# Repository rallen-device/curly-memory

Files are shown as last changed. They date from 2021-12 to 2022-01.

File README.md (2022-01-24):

# CURLY-MEMORY

Open source eurorack hardware using an ESP32.

ESP32 acts like anything you want, just reprogram with new firmware.

## Features

### INPUTS:
 - Analogue input x4
  - 1/8" jack x3 (IN0, IN1, IN2)
  - 2.54mm pin header x2 (IN2, IN3)

### OUTPUTS:
 - Analogue output x4
  - 1/8" jack x3 (OUT0, OUT1, OUT2)
  - 2.54mm pin header x3 (OUT2, OUT3)

### CONTROLS:
 - Potentiometer input x4
 - Tactile switch x2

### OTHER:
 - Feedback resistor (digital pot connecting OUT0 to IN0)
 - Digital pot output on 2.54mm pin header
 - Dry/wet mixer (IN0 + OUT0 - connecting to digital pot)
 - WS2812B LEDs x2

### POWER:
 - Eurorack standard 10 pin IDC connector
 - 12V input

### FIRMWARE:
 - ESP-IDF or Arduino

## Images

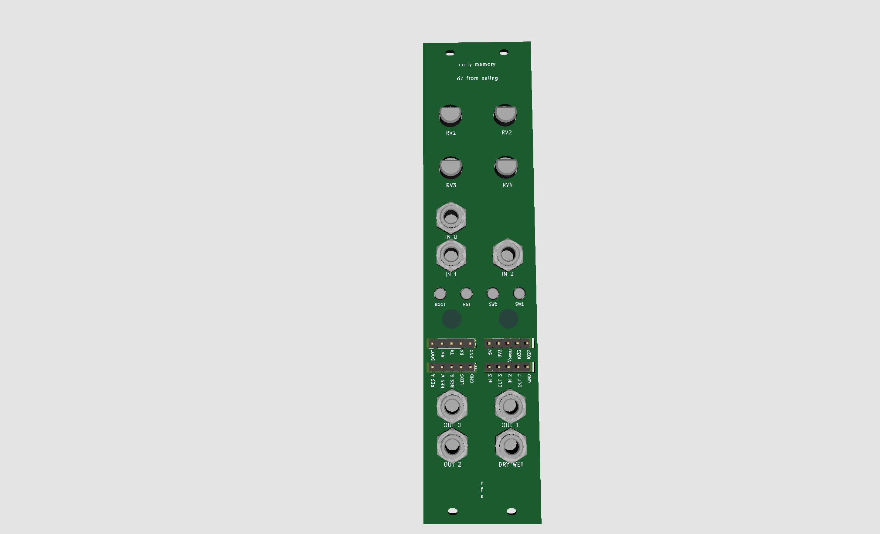
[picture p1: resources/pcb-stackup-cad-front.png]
main-cad

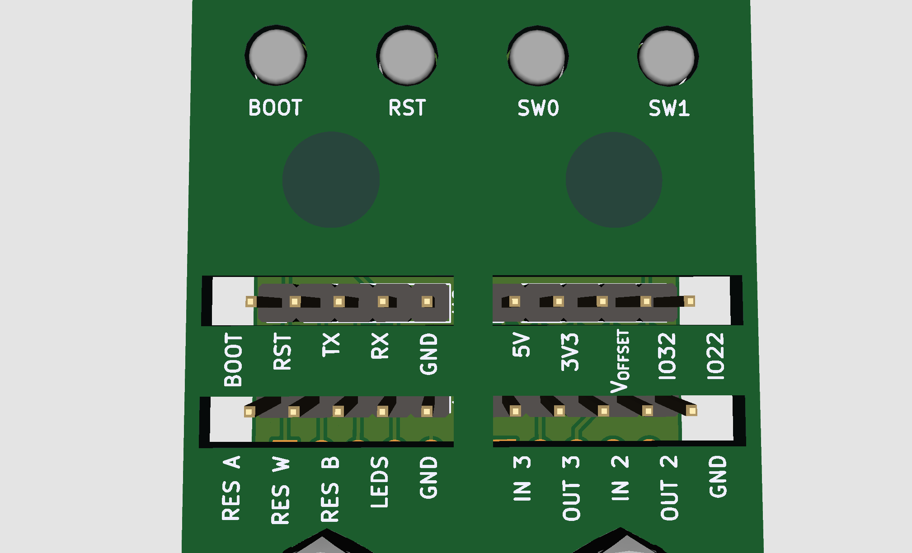
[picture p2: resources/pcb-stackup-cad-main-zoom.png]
zoom-cad

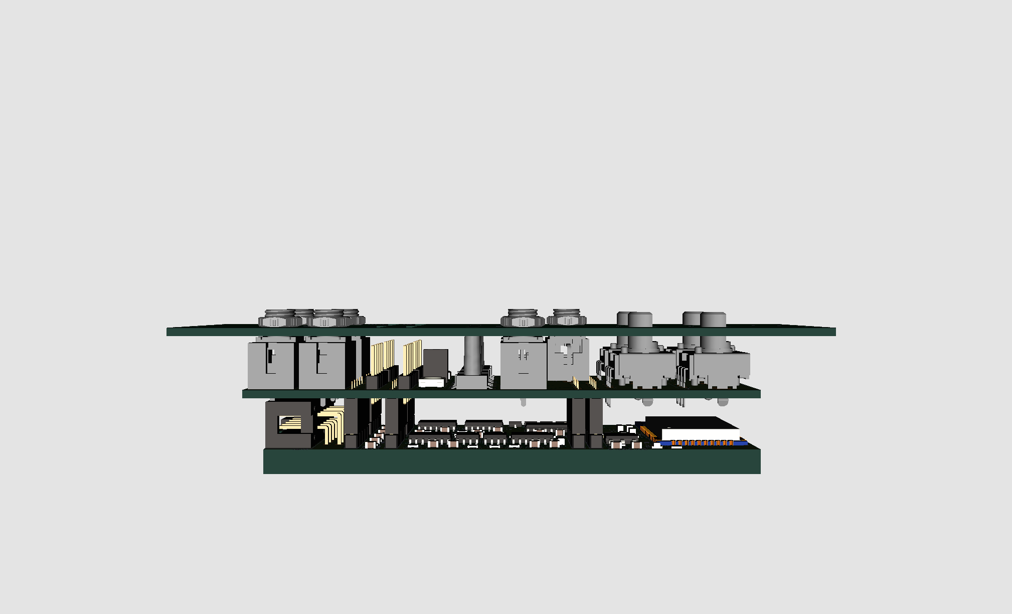
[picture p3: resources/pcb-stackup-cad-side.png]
side-cad


## References

- https://www.electrosmash.com/pt2399-analysis
- https://intellijel.com/support/eurorack-101/
- https://docs.espressif.com/projects/esp-idf/en/latest/esp32/api-reference/peripherals/spi_master.html

## Influences

- https://ornament-and-cri.me/

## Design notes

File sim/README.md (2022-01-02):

# Simulations

All simulations are done using http://www.falstad.com/circuit/, open the files on the website to view the simulations

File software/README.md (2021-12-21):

# Firmware

Firmware runs on an esp32. The firmware is open source and can be modified to change the functionality.

## Installation and Usage

- Clone this repo
- Install esp-idf to compile
- Run ~/esp/esp-idf/export.sh to import the idf tools to the command line
- Run idf.py build to build the code

Follow the steps on ['ESP-IDF Get Started'](https://docs.espressif.com/projects/esp-idf/en/latest/esp32/get-started/index.html#installation-step-by-step) to install the esp-idf which is used to compile.

## Troubleshooting

#### Installing esp-idf on macos

Only version that worked was 'release/v4.2' to get this run the following commands:
$ git checkout --track origin/release/v4.2
$ git submodule update --recursive

#### USB device not showing up on macos

- Install CP2102 driver from https://www.silabs.com/developers/usb-to-uart-bridge-vcp-drivers
- During install it request to 'Open Security and Privacy', open it and click the lock in the bottom left, then click allow where it says that VCP driver is requesting to make changes

# Licence
For licence see main readme

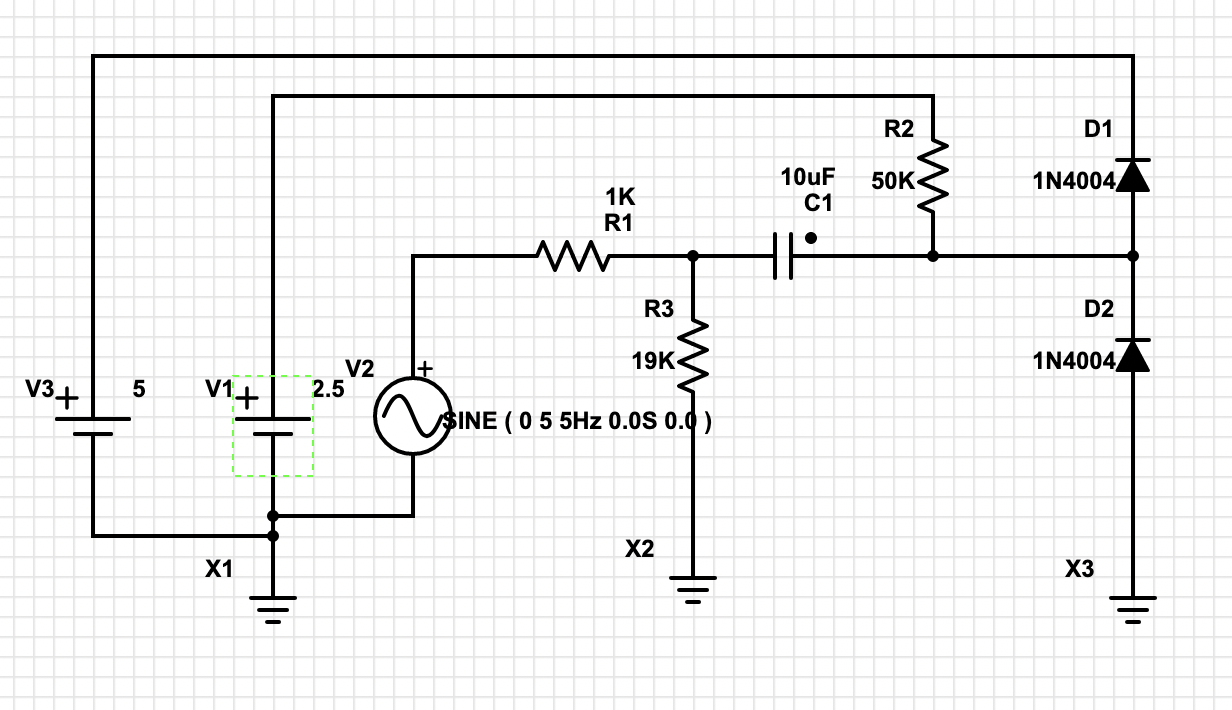
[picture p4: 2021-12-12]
resources/osc_in_circuit.png

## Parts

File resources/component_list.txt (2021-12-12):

ADC - option a - https://www.ti.com/store/ti/en/p/product/?p=ADC082S021CIMM/NOPB
ADC - option b - https://uk.farnell.com/microchip/mcp3002-i-sn/adc-10bit-2-7v-2ch-spi-8soic/dp/1834969?st=mcp3002
1/8 Jack - ACJM-MV35-2S - https://uk.farnell.com/amphenol-sine-tuchel/acjm-mv35-2s/phone-connector-mono-jack-2pos/dp/3280971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

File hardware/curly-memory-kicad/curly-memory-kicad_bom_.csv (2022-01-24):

Component | Part | Description | References | Value | Footprint | Quantity Per PCB | Datasheet | MF | MFPN | Material | Voltage | Tolerance
1 | C | Unpolarized capacitor | C201 C202 C203 C301 C302 C303 | 22pF | C_0805_2012Metric_Pad1.18x1.45mm_HandSolder | 6 |  | Samsung | CL21C220JBANNNC | CG0 / NP0 | 50V
2 | C_2 | Unpolarized capacitor | C101 C103 C104 C105 C106 C108 C109 C206 C207 C309 C310 C401 C408 | 100nF | C_0805_2012Metric_Pad1.18x1.45mm_HandSolder | 13 | ~ | Samsung | CL21B104KBCNNNC | X7R | 50V
3 | C |  | C102 C110 C304 C305 C306 | 1uF | C_0805_2012Metric_Pad1.18x1.45mm_HandSolder | 5 |  | Samsung | CL21B105KBFNNNE | X7R | 50V
4 | C |  | C402 C403 C404 C409 C410 | 10uF | C_0805_2012Metric_Pad1.18x1.45mm_HandSolder | 5 |  | Murata | GRM21BR61H106KE43L | X5R | 50V
5 | BAV99 |  | D201 D202 D203 D204 | BAV99 | SOT-23 | 4 | https://assets.nexperia.com/documents/data-sheet/BAV99_SER.pdf
6 | LED | Light emitting diode | D403 D404 | LED | LED_0805_2012Metric_Pad1.15x1.40mm_HandSolder | 2 | ~ | Kingbright | KP-2012EC
7 | D |  | D401 D402 | S1A | D_SMA | 2
8 | R | Resistor | R107 R207 R208 R209 | 100R | R_0805_2012Metric_Pad1.20x1.40mm_HandSolder | 4 | ~ | Multicomp | MCWR08X1000FTL |  |  | 1%
9 | R | Resistor | R403 R404 | 150R | R_0805_2012Metric_Pad1.20x1.40mm_HandSolder | 2 | ~ | Multicomp | MCWR08X1500FTL |  |  | 1%
10 | R_1 | Resistor | R101 R102 R103 R104 R105 R106 | 1K | R_0805_2012Metric_Pad1.20x1.40mm_HandSolder | 6 | ~ | Multicomp | MCWR08X1001FTL |  |  | 1%
11 | R | Resistor | R204 R205 R206 R301 R302 R303 | 47K | R_0805_2012Metric_Pad1.20x1.40mm_HandSolder | 6 | ~ | Multicomp | MCWR08X4702FTL |  |  | 1%
12 | R | Resistor | R402 | 56K | R_0805_2012Metric_Pad1.20x1.40mm_HandSolder | 1 | ~ | Multicomp | MCWR08X5602FTL |  |  | 1%
13 | R | Resistor | R108 R201 R202 R203 R304 R305 R306 R307 R308 R309 R401 | 100K | R_0805_2012Metric_Pad1.20x1.40mm_HandSolder | 11 | ~ | Multicomp | MCWR08X1003FTL |  |  | 1%
14 | ESP32-WROOM-32 |  | U102 | ESP32-WROOM-32 | ESP32-WROOM-32 | 1 | https://www.espressif.com/sites/default/files/documentation/esp32-wroom-32_datasheet_en.pdf
15 | MCP3008 |  | U101 | MCP3008-I/SL | SOIC-16_3.9x9.9mm_P1.27mm | 1 | http://ww1.microchip.com/downloads/en/DeviceDoc/21295d.pdf
16 | MCP42010 | Dual Digital Potentiometer, SPI interface, 256 taps, 10 kohm | U105 U106 | MCP42010-I/SL | SOIC-14_3.9x8.7mm_P1.27mm | 2 | http://ww1.microchip.com/downloads/en/DeviceDoc/11195c.pdf
17 | MCP4822 |  | U103 U104 | MCP4822-E/SN | SOIC-8_3.9x4.9mm_P1.27mm | 2 | http://ww1.microchip.com/downloads/en/DeviceDoc/20002249B.pdf
18 | MCP6004 | 1MHz, Low-Power Op Amp, DIP-14/SOIC-14/TSSOP-14 | U201 U301 | MCP6004-I/SL | SOIC-14_3.9x8.7mm_P1.27mm | 2 | http://ww1.microchip.com/downloads/en/DeviceDoc/21733j.pdf
19 | NCP1117-3.3_SOT223 | 1A Low drop-out regulator, Fixed Output 3.3V, SOT-223 | U402 | NCP1117-3.3_SOT223 | SOT-223-3_TabPin2 | 1 | http://www.onsemi.com/pub_link/Collateral/NCP1117-D.PDF | STMICROELECTRONICS | LD1117S33TR |  | 3V3
20 | NCP1117-5.0_SOT223 | 1A Low drop-out regulator, Fixed Output 5V, SOT-223 | U401 | NCP1117-5.0_SOT223 | SOT-223-3_TabPin2 | 1 | http://www.onsemi.com/pub_link/Collateral/NCP1117-D.PDF | STMICROELECTRONICS | LD1117S50TR |  | 5V
Component Groups: | 20
Component Count: | 77
Fitted Components: | 77
Number of PCBs: | 1
Total components: | 77
Schematic Version:
Schematic Date:
PCB Variant: | default
BoM Date: | Sunday, 16 January 2022 at 09:43:23
Schematic Source: | curly-memory-kicad.kicad_sch
KiCad Version: | Eeschema (6.0.0-0)

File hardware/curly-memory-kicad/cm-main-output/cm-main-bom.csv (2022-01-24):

Component | Description | References | Value | Footprint | Quantity Per PCB | Datasheet | MF | MFPN | Material | Voltage | Tolerance
1 | Unpolarized capacitor | C201 C202 C203 C301 C302 C303 | 22pF | C_0805_2012Metric_Pad1.18x1.45mm_HandSolder | 6 |  | Samsung | CL21C220JBANNNC | CG0 / NP0 | 50V
2 | Unpolarized capacitor | C101 C103 C104 C105 C106 C108 C109 C206 C207 C309 C310 C401 C408 | 100nF | C_0805_2012Metric_Pad1.18x1.45mm_HandSolder | 13 | ~ | Samsung | CL21B104KBCNNNC | X7R | 50V
3 | Unpolarized capacitor | C102 C110 C304 C305 C306 | 1uF | C_0805_2012Metric_Pad1.18x1.45mm_HandSolder | 5 |  | Samsung | CL21B105KBFNNNE | X7R | 50V
4 | Unpolarized capacitor | C402 C403 C404 C409 C410 | 10uF | C_0805_2012Metric_Pad1.18x1.45mm_HandSolder | 5 |  | Murata | GRM21BR61H106KE43L | X5R | 50V
5 | BAV99 Diode | D201 D202 D203 D204 | BAV99 | SOT-23 | 4 | https://assets.nexperia.com/documents/data-sheet/BAV99_SER.pdf | ROHM | BAV99HMT116
6 | Light emitting diode | D403 D404 | LED | LED_0805_2012Metric_Pad1.15x1.40mm_HandSolder | 2 | ~ | Kingbright | KP-2012EC
7 | S1A Diode | D401 D402 | S1A | D_SMA | 2 |  | Vishay | S1A-E3/61T
8 | Resistor | R107 R207 R208 R209 | 100R | R_0805_2012Metric_Pad1.20x1.40mm_HandSolder | 4 | ~ | Multicomp | MCWR08X1000FTL |  |  | 1%
9 | Resistor | R403 R404 | 150R | R_0805_2012Metric_Pad1.20x1.40mm_HandSolder | 2 | ~ | Multicomp | MCWR08X1500FTL |  |  | 1%
10 | Resistor | R101 R102 R103 R104 R105 R106 | 1K | R_0805_2012Metric_Pad1.20x1.40mm_HandSolder | 6 | ~ | Multicomp | MCWR08X1001FTL |  |  | 1%
11 | Resistor | R204 R205 R206 R301 R302 R303 | 47K | R_0805_2012Metric_Pad1.20x1.40mm_HandSolder | 6 | ~ | Multicomp | MCWR08X4702FTL |  |  | 1%
12 | Resistor | R402 | 56K | R_0805_2012Metric_Pad1.20x1.40mm_HandSolder | 1 | ~ | Multicomp | MCWR08X5602FTL |  |  | 1%
13 | Resistor | R108 R201 R202 R203 R304 R305 R306 R307 R308 R309 R401 | 100K | R_0805_2012Metric_Pad1.20x1.40mm_HandSolder | 11 | ~ | Multicomp | MCWR08X1003FTL |  |  | 1%
14 | ESP32 WROOM | U102 | ESP32-WROOM-32 | ESP32-WROOM-32 | 1 | https://www.espressif.com/sites/default/files/documentation/esp32-wroom-32_datasheet_en.pdf | Espressif | ESP32-WROOM-32E
15 | Analog to Digital Converters - ADC 10-bit SPI 8 Chl IND TEMP, SOIC16 | U101 | MCP3008-I/SL | SOIC-16_3.9x9.9mm_P1.27mm | 1 | http://ww1.microchip.com/downloads/en/DeviceDoc/21295d.pdf | Microchip | MCP3008-I/SL
16 | Dual Digital Potentiometer, SPI interface, 256 taps, 10 kohm | U105 U106 | MCP42010-I/SL | SOIC-14_3.9x8.7mm_P1.27mm | 2 | http://ww1.microchip.com/downloads/en/DeviceDoc/11195c.pdf | Microchip | MCP42010-I/SL
17 | Digital to Analog Converters - DAC Dual 12-bit DAC | U103 U104 | MCP4822-E/SN | SOIC-8_3.9x4.9mm_P1.27mm | 2 | http://ww1.microchip.com/downloads/en/DeviceDoc/20002249B.pdf | Microchip | MCP4822-E/SN
18 | 1MHz, Low-Power Op Amp, DIP-14/SOIC-14/TSSOP-14 | U201 U301 | MCP6004-I/SL | SOIC-14_3.9x8.7mm_P1.27mm | 2 | http://ww1.microchip.com/downloads/en/DeviceDoc/21733j.pdf | Microchip | MCP6004-I/SL
19 | 1A Low drop-out regulator, Fixed Output 3.3V, SOT-223 | U402 | NCP1117-3.3_SOT223 | SOT-223-3_TabPin2 | 1 | http://www.onsemi.com/pub_link/Collateral/NCP1117-D.PDF | STMICROELECTRONICS | LD1117S33TR |  | 3V3
20 | 1A Low drop-out regulator, Fixed Output 5V, SOT-223 | U401 | NCP1117-5.0_SOT223 | SOT-223-3_TabPin2 | 1 | http://www.onsemi.com/pub_link/Collateral/NCP1117-D.PDF | STMICROELECTRONICS | LD1117S50TR |  | 5V
Component Groups:
Component Count:
Fitted Components:
Number of PCBs:
Total components:
Schematic Version:
Schematic Date:
PCB Variant:
BoM Date:
Schematic Source:
KiCad Version:

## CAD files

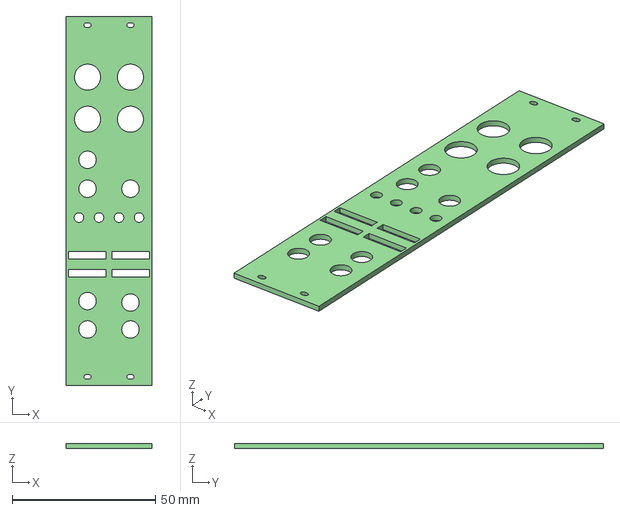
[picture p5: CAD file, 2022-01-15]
hardware/curly-memory-face-plate/curly-memory-face-plate-a0.step
30.0 x 129.0 x 1.60 mm

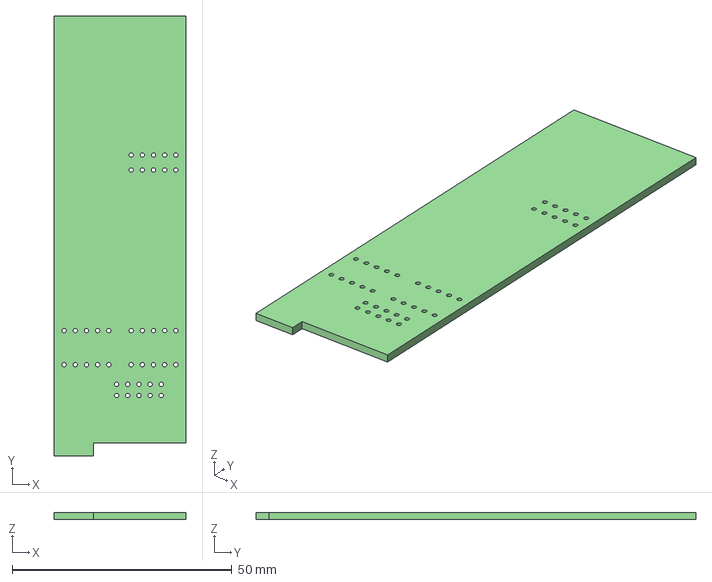
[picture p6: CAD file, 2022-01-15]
hardware/curly-memory-kicad/curly-memory-kicad-a0.step
30.0 x 100.0 x 1.60 mm

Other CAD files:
hardware/curly-memory-assembly 3.FCStd
hardware/curly-memory-assembly.FCStd

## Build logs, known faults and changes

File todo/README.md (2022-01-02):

# TODO

- Add values to all components
- Find components for standard parts (e.g. tactile switch) and add to schematic
- Add USB connector/IC for programming

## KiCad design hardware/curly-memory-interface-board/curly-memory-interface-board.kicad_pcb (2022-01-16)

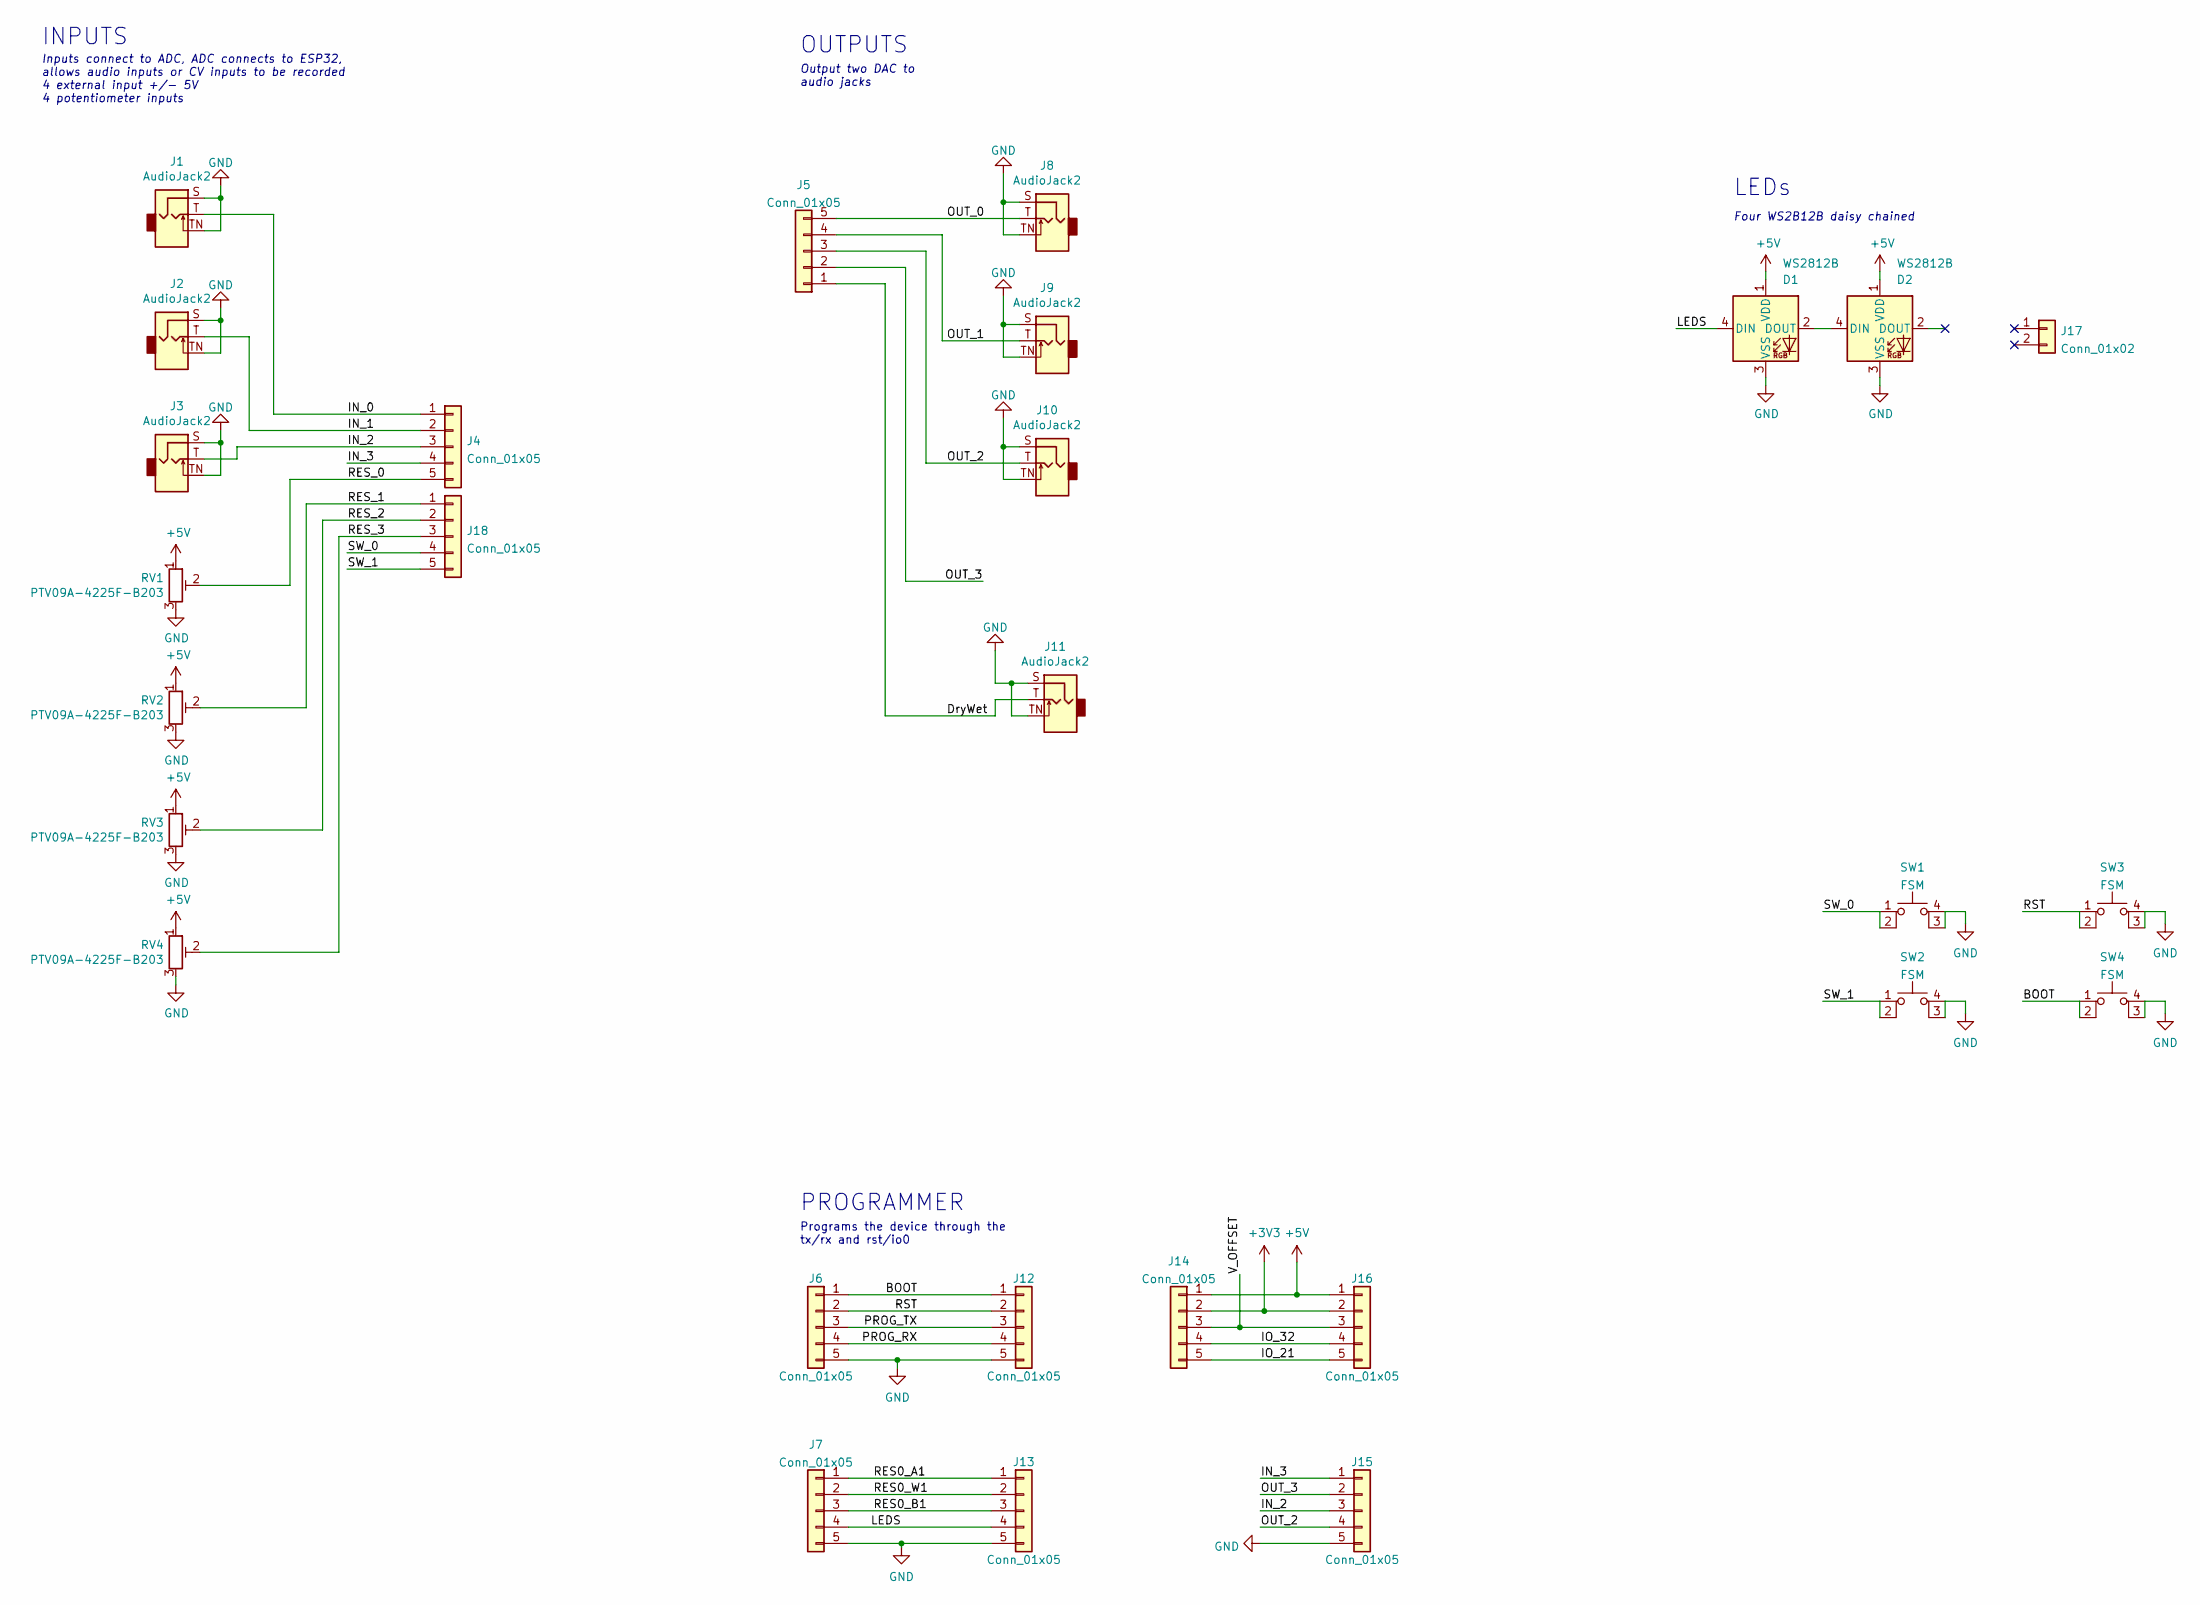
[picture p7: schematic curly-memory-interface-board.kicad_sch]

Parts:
D1, D2: WS2812B; LED_WS2812B_PLCC4_5.0x5.0mm_P3.2mm
J1, J2, J3, J8, J9, J10, J11: AudioJack2; Jack_3.5mm_QingPu_WQP-PJ398SM_Vertical
J4, J5, J6, J7, J14, J18: Conn_01x05; PinSocket_1x05_P2.54mm_Vertical
J12, J13, J15, J16: Conn_01x05; PinHeader_1x05_P2.54mm_Vertical
J17: Conn_01x02; PinSocket_1x02_P2.54mm_Vertical
RV1, RV2, RV3, RV4: PTV09A-4225F-B203; Potentiometer_Bourns_PTV09A-1_Single_Vertical
SW1, SW2, SW3, SW4: FSM; SW_Push_1P1T_NO_6x6mm_H9.5mm

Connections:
+3V3: J14.2, J16.2
+5V: D1.1 (VDD), D2.1 (VDD), J14.1, J16.1, RV1.1, RV2.1, RV3.1, RV4.1
/BOOT: J6.1, J12.1, SW4.1, SW4.2
/DryWet: J5.1, J11.T
/IN_0: J1.T, J4.1
/IN_1: J2.T, J4.2
/IN_2: J3.T, J4.3, J15.3
/IN_3: J4.4, J15.1
/IO_21: J14.5, J16.5
/IO_32: J14.4, J16.4
/LEDS: D1.4 (DIN), J7.4, J13.4
/OUT_0: J5.5, J8.T
/OUT_1: J5.4, J9.T
/OUT_2: J5.3, J10.T, J15.4
/OUT_3: J5.2, J15.2
/PROG_RX: J6.4, J12.4
/PROG_TX: J6.3, J12.3
/RES0_A1: J7.1, J13.1
/RES0_B1: J7.3, J13.3
/RES0_W1: J7.2, J13.2
/RES_0: J4.5, RV1.2
/RES_1: J18.1, RV2.2
/RES_2: J18.2, RV3.2
/RES_3: J18.3, RV4.2
/RST: J6.2, J12.2, SW3.1, SW3.2
/SW_0: J18.4, SW1.1, SW1.2
/SW_1: J18.5, SW2.1, SW2.2
/V_OFFSET: J14.3, J16.3
GND: D1.3 (VSS), D2.3 (VSS), J1.S, J1.TN, J2.S, J2.TN, J3.S, J3.TN, J6.5, J7.5, J8.S, J8.TN, J9.S, J9.TN, J10.S, J10.TN, J11.S, J11.TN, J12.5, J13.5, J15.5, RV1.3, RV2.3, RV3.3, RV4.3, SW1.3 (K), SW1.4 (A), SW2.3 (K), SW2.4 (A), SW3.3 (K), SW3.4 (A), SW4.3 (K), SW4.4 (A)
unnamed: D1.2 (DOUT), D2.4 (DIN)

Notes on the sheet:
INPUTS
OUTPUTS
LEDs
Programs the device through the tx/rx and rst/io0
Output two DAC to audio jacks
Four WS2B12B daisy chained
PROGRAMMER
Inputs connect to ADC, ADC connects to ESP32, allows audio inputs or CV inputs to be recorded 4 external input +/- 5V 4 potentiometer inputs

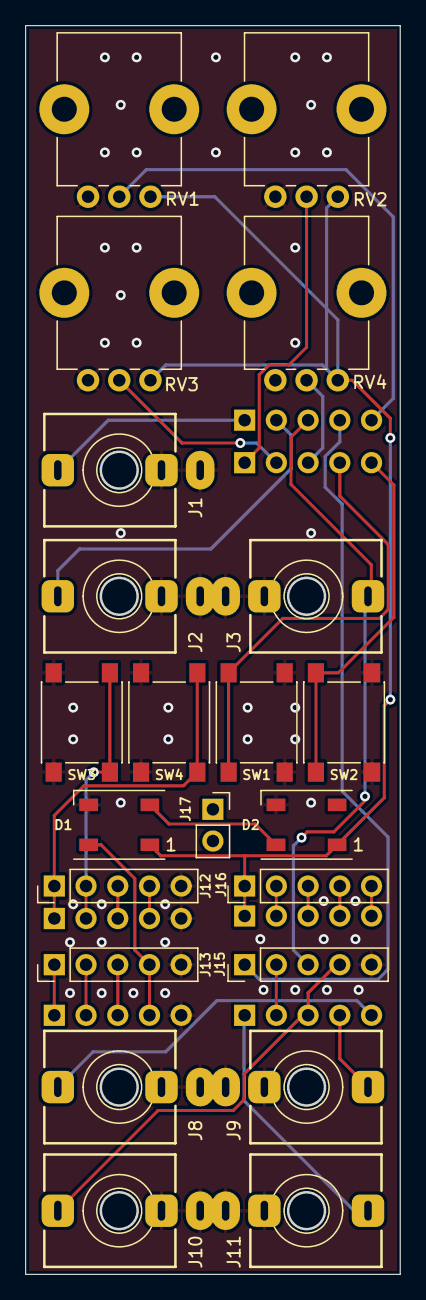
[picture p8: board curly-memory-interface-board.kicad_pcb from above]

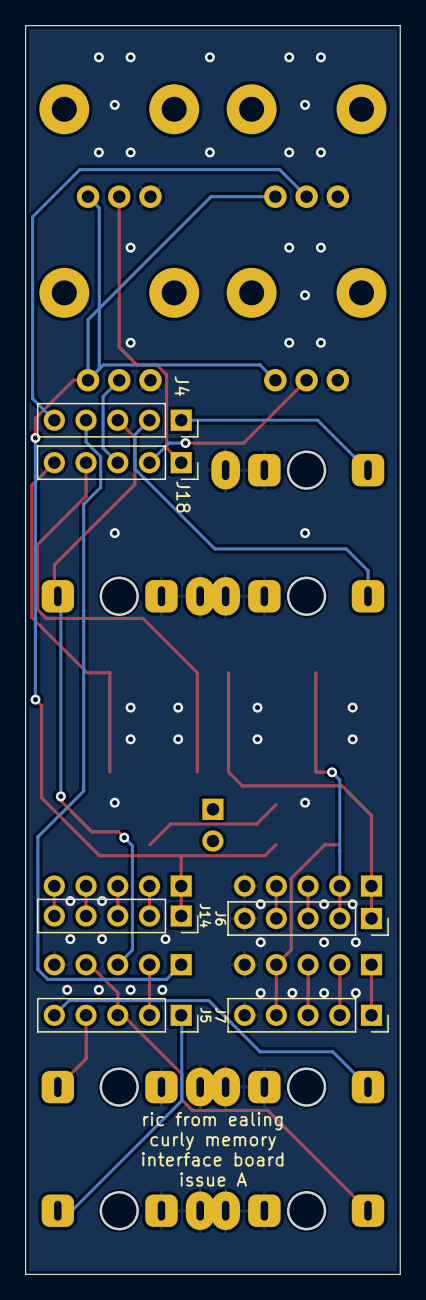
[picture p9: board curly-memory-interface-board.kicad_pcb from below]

Board: 2 copper layers, 30.0 x 100.0 mm, 28 parts (6 on the bottom side), 30 nets.

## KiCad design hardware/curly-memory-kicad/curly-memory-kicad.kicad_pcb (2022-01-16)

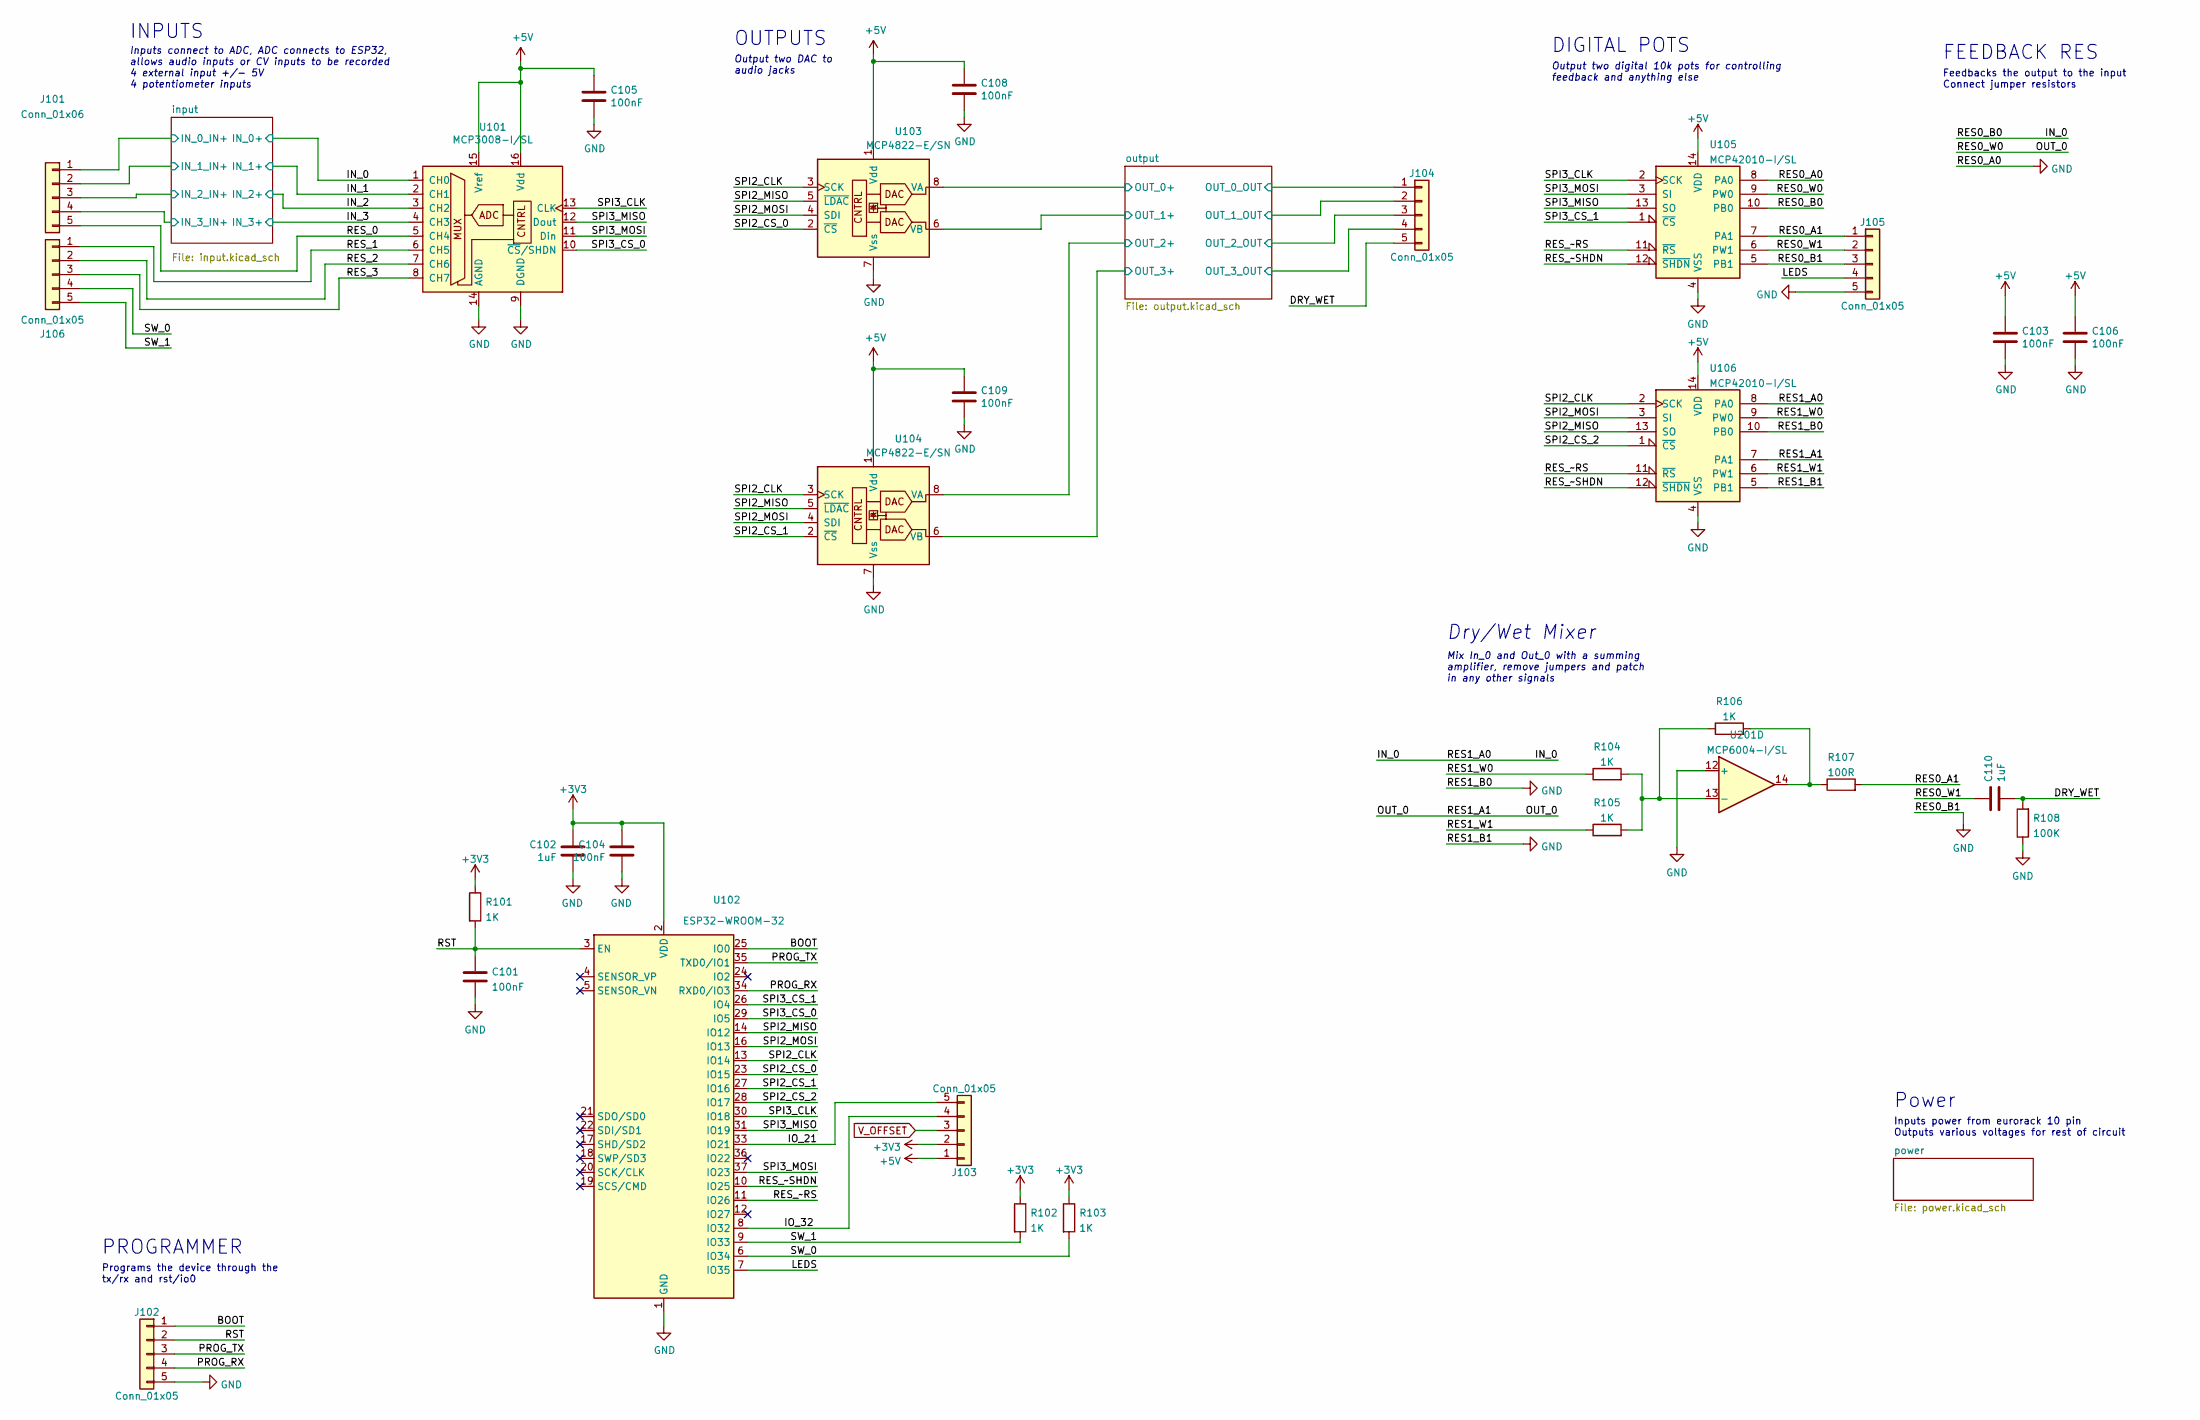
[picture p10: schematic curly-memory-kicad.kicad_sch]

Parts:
C101, C103, C104, C105, C106, C108, C109: 100nF; C_0805_2012Metric_Pad1.18x1.45mm_HandSolder; Voltage 50V
C102, C110: 1uF; C_0805_2012Metric_Pad1.18x1.45mm_HandSolder; Voltage 50V
J101: Conn_01x06; PinHeader_1x05_P2.54mm_Vertical
J102, J103, J104, J105, J106: Conn_01x05; PinHeader_1x05_P2.54mm_Vertical
R101, R102, R103, R104, R105, R106: 1K; R_0805_2012Metric_Pad1.20x1.40mm_HandSolder; Tolerance 1%
R107: 100R; R_0805_2012Metric_Pad1.20x1.40mm_HandSolder; Tolerance 1%
R108: 100K; R_0805_2012Metric_Pad1.20x1.40mm_HandSolder; Tolerance 1%
U101: MCP3008-I/SL; SOIC-16_3.9x9.9mm_P1.27mm
U102: ESP32-WROOM-32
U103, U104: MCP4822-E/SN; SOIC-8_3.9x4.9mm_P1.27mm
U105, U106: MCP42010-I/SL; SOIC-14_3.9x8.7mm_P1.27mm
U201: MCP6004-I/SL; SOIC-14_3.9x8.7mm_P1.27mm

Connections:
+3V3: C102.1, C104.1, J103.2, R101.1, R102.1, R103.1, U102.2 (VDD); also elsewhere on the board
+5V: C103.1, C105.1, C106.1, C108.1, C109.1, J103.1, U101.15 (Vref), U101.16 (Vdd), U103.1 (Vdd), U104.1 (Vdd), U105.14 (VDD), U106.14 (VDD); also elsewhere on the board
/BOOT: J102.1, U102.25 (IO0)
/DRY_WET: C110.2, J104.5, R108.2
/IN_0: U101.1 (CH0), U105.10 (PB0), U106.8 (PA0); also elsewhere on the board
/IN_1: U101.2 (CH1); also elsewhere on the board
/IN_2: U101.3 (CH2); also elsewhere on the board
/IN_3: J101.4, U101.4 (CH3); also elsewhere on the board
/IO_21: J103.5, U102.33 (IO21)
/IO_32: J103.4, U102.8 (IO32)
/LEDS: J105.4, U102.7 (IO35)
/OUT_0: U105.9 (PW0), U106.7 (PA1)
/PROG_RX: J102.4, U102.34 (RXD0/IO3)
/PROG_TX: J102.3, U102.35 (TXD0/IO1)
/RES0_A1: J105.1, R107.2, U105.7 (PA1)
/RES0_W1: C110.1, J105.2, U105.6 (PW1)
/RES1_W0: R104.1, U106.9 (PW0)
/RES1_W1: R105.1, U106.6 (PW1)
/RES_0: J101.5, U101.5 (CH4)
/RES_1: J106.1, U101.6 (CH5)
/RES_2: J106.2, U101.7 (CH6)
/RES_3: J106.3, U101.8 (CH7)
/RES_~RS: U102.11 (IO26), U105.11 (~RS), U106.11 (~RS)
/RES_~SHDN: U102.10 (IO25), U105.12 (~SHDN), U106.12 (~SHDN)
/RST: C101.1, J102.2, R101.2, U102.3 (EN)
/SPI2_CLK: U102.13 (IO14), U103.3 (SCK), U104.3 (SCK), U106.2 (SCK)
/SPI2_CS_0: U102.23 (IO15), U103.2 (~CS)
/SPI2_CS_1: U102.27 (IO16), U104.2 (~CS)
/SPI2_CS_2: U102.28 (IO17), U106.1 (~CS)
/SPI2_MISO: U102.14 (IO12), U103.5 (~LDAC), U104.5 (~LDAC), U106.13 (SO)
/SPI2_MOSI: U102.16 (IO13), U103.4 (SDI), U104.4 (SDI), U106.3 (SI)
/SPI3_CLK: U101.13 (CLK), U102.30 (IO18), U105.2 (SCK)
/SPI3_CS_0: U101.10 (~CS/SHDN), U102.29 (IO5)
/SPI3_CS_1: U102.26 (IO4), U105.1 (~CS)
/SPI3_MISO: U101.12 (Dout), U102.31 (IO19), U105.13 (SO)
/SPI3_MOSI: U101.11 (Din), U102.37 (IO23), U105.3 (SI)
/SW_0: J106.4, R103.2, U102.6 (IO34)
/SW_1: J106.5, R102.2, U102.9 (IO33)
/input/IN_0_IN+: J101.1; also elsewhere on the board
/input/IN_1_IN+: J101.2; also elsewhere on the board
/input/IN_2_IN+: J101.3; also elsewhere on the board
/output/OUT_0+: U103.8 (VA); also elsewhere on the board
/output/OUT_0_OUT: J104.1; also elsewhere on the board
/output/OUT_1+: U103.6 (VB); also elsewhere on the board
/output/OUT_1_OUT: J104.2; also elsewhere on the board
/output/OUT_2+: U104.8 (VA); also elsewhere on the board
/output/OUT_2_OUT: J104.3; also elsewhere on the board
/output/OUT_3+: J104.4, U104.6 (VB)
GND: C101.2, C102.2, C103.2, C104.2, C105.2, C106.2, C108.2, C109.2, J102.5, J105.3, J105.5, R108.1, U101.9 (DGND), U101.14 (AGND), U102.1 (GND), U102.15 (GND), U102.38 (GND), U102.39 (GND), U103.7 (Vss), U104.7 (Vss), U105.4 (VSS), U105.5 (PB1), U105.8 (PA0), U106.4 (VSS), U106.5 (PB1), U106.10 (PB0), U201.12 (+); also elsewhere on the board
unnamed: R104.2, R105.2, R106.1, U201.13 (-)
unnamed: R106.2, R107.1, U201.14
V_OFFSET: J103.3; also elsewhere on the board

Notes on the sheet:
DIGITAL POTS
Inputs power from eurorack 10 pin Outputs various voltages for rest of circuit
INPUTS
FEEDBACK RES
Power
Output two digital 10k pots for controlling feedback and anything else
OUTPUTS
Programs the device through the tx/rx and rst/io0
Output two DAC to audio jacks
Mix In_0 and Out_0 with a summing amplifier, remove jumpers and patch in any other signals
PROGRAMMER
Dry/Wet Mixer
Inputs connect to ADC, ADC connects to ESP32, allows audio inputs or CV inputs to be recorded 4 external input +/- 5V 4 potentiometer inputs
Feedbacks the output to the input Connect jumper resistors

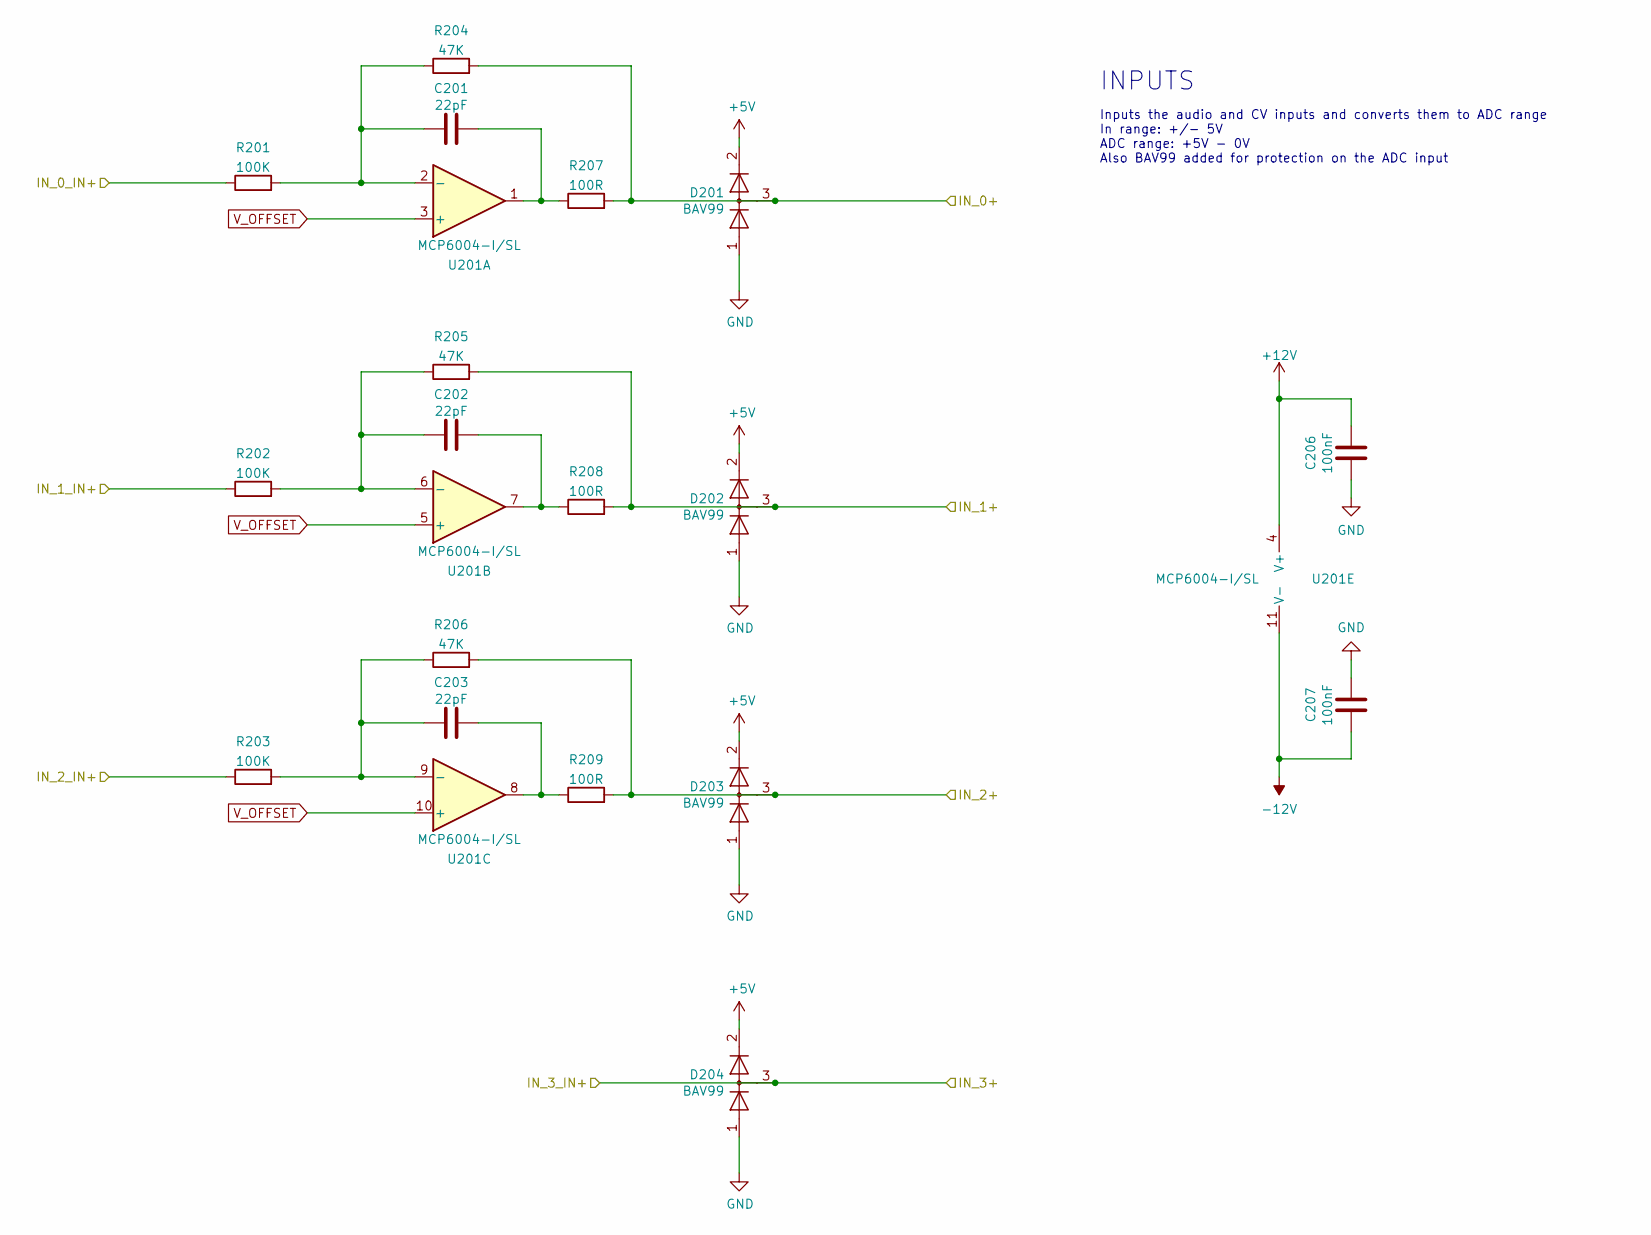
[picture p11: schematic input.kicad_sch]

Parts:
C201, C202, C203: 22pF; C_0805_2012Metric_Pad1.18x1.45mm_HandSolder; Voltage 50V
C206, C207: 100nF; C_0805_2012Metric_Pad1.18x1.45mm_HandSolder; Voltage 50V
D201, D202, D203, D204: BAV99; SOT-23
R201, R202, R203: 100K; R_0805_2012Metric_Pad1.20x1.40mm_HandSolder; Tolerance 1%
R204, R205, R206: 47K; R_0805_2012Metric_Pad1.20x1.40mm_HandSolder; Tolerance 1%
R207, R208, R209: 100R; R_0805_2012Metric_Pad1.20x1.40mm_HandSolder; Tolerance 1%
U201: MCP6004-I/SL; SOIC-14_3.9x8.7mm_P1.27mm

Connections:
+5V: D201.2 (A), D202.2 (A), D203.2 (A), D204.2 (A); also elsewhere on the board
+12V: C206.1, U201.4 (V+); also elsewhere on the board
-12V: C207.1, U201.11 (V-); also elsewhere on the board
/IN_0: D201.3 (K), R204.2, R207.2; also elsewhere on the board
/IN_1: D202.3 (K), R205.2, R208.2; also elsewhere on the board
/IN_2: D203.3 (K), R206.2, R209.2; also elsewhere on the board
/IN_3: D204.3 (K); also elsewhere on the board
/input/IN_0_IN+: R201.1; also elsewhere on the board
/input/IN_1_IN+: R202.1; also elsewhere on the board
/input/IN_2_IN+: R203.1; also elsewhere on the board
GND: C206.2, C207.2, D201.1 (K), D202.1 (K), D203.1 (K), D204.1 (K); also elsewhere on the board
unnamed: C201.1, R207.1, U201.1
unnamed: C201.2, R201.2, R204.1, U201.2 (-)
unnamed: C202.1, R208.1, U201.7
unnamed: C202.2, R202.2, R205.1, U201.6 (-)
unnamed: C203.1, R209.1, U201.8
unnamed: C203.2, R203.2, R206.1, U201.9 (-)
V_OFFSET: U201.3 (+), U201.5 (+), U201.10 (+); also elsewhere on the board

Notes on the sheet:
Inputs the audio and CV inputs and converts them to ADC range In range: +/- 5V ADC range: +5V - 0V Also BAV99 added for protection on the ADC input
INPUTS

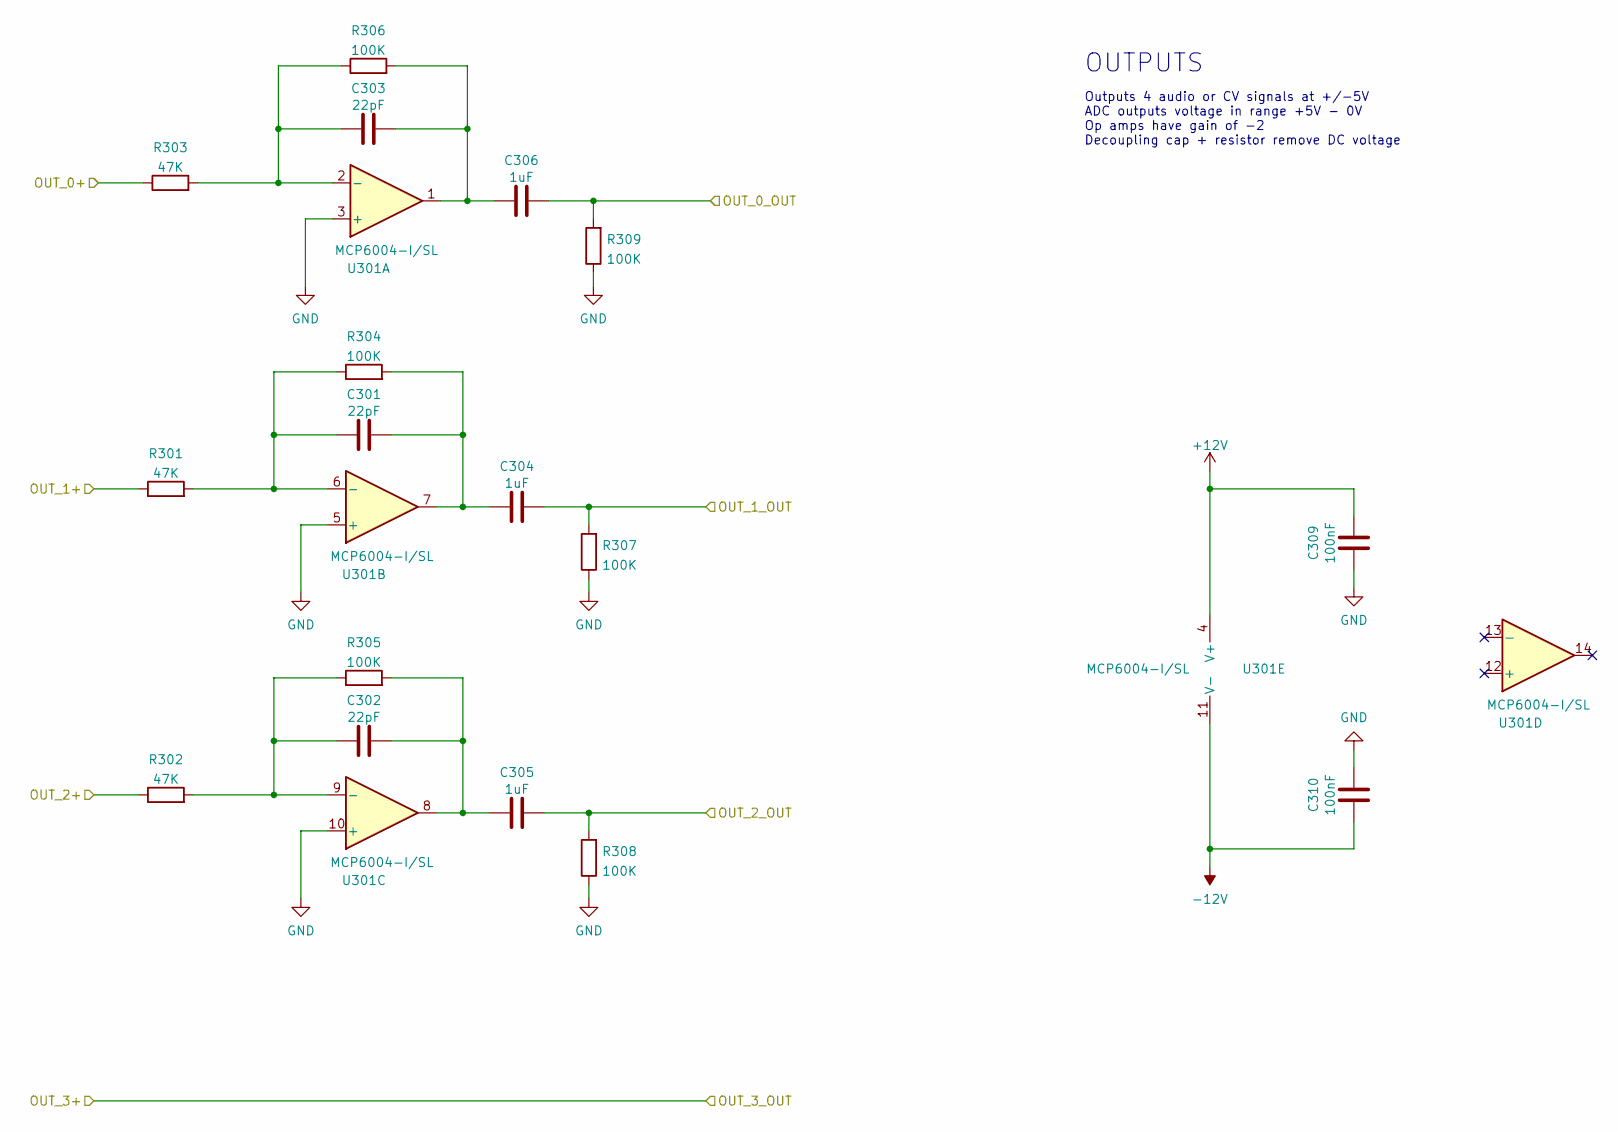
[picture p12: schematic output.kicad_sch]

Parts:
C301, C302, C303: 22pF; C_0805_2012Metric_Pad1.18x1.45mm_HandSolder; Voltage 50V
C304, C305, C306: 1uF; C_0805_2012Metric_Pad1.18x1.45mm_HandSolder; Voltage 50V
C309, C310: 100nF; C_0805_2012Metric_Pad1.18x1.45mm_HandSolder; Voltage 50V
R301, R302, R303: 47K; R_0805_2012Metric_Pad1.20x1.40mm_HandSolder; Tolerance 1%
R304, R305, R306, R307, R308, R309: 100K; R_0805_2012Metric_Pad1.20x1.40mm_HandSolder; Tolerance 1%
U301: MCP6004-I/SL; SOIC-14_3.9x8.7mm_P1.27mm

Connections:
+12V: C309.1, U301.4 (V+); also elsewhere on the board
-12V: C310.1, U301.11 (V-); also elsewhere on the board
/output/OUT_0+: R303.1; also elsewhere on the board
/output/OUT_0_OUT: C306.1, R309.2; also elsewhere on the board
/output/OUT_1+: R301.1; also elsewhere on the board
/output/OUT_1_OUT: C304.1, R307.2; also elsewhere on the board
/output/OUT_2+: R302.1; also elsewhere on the board
/output/OUT_2_OUT: C305.1, R308.2; also elsewhere on the board
GND: C309.2, C310.2, R307.1, R308.1, R309.1, U301.3 (+), U301.5 (+), U301.10 (+); also elsewhere on the board
unnamed: C301.1, C304.2, R304.2, U301.7
unnamed: C301.2, R301.2, R304.1, U301.6 (-)
unnamed: C302.1, C305.2, R305.2, U301.8
unnamed: C302.2, R302.2, R305.1, U301.9 (-)
unnamed: C303.1, C306.2, R306.2, U301.1
unnamed: C303.2, R303.2, R306.1, U301.2 (-)

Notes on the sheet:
OUTPUTS
Outputs 4 audio or CV signals at +/-5V ADC outputs voltage in range +5V - 0V Op amps have gain of -2 Decoupling cap + resistor remove DC voltage

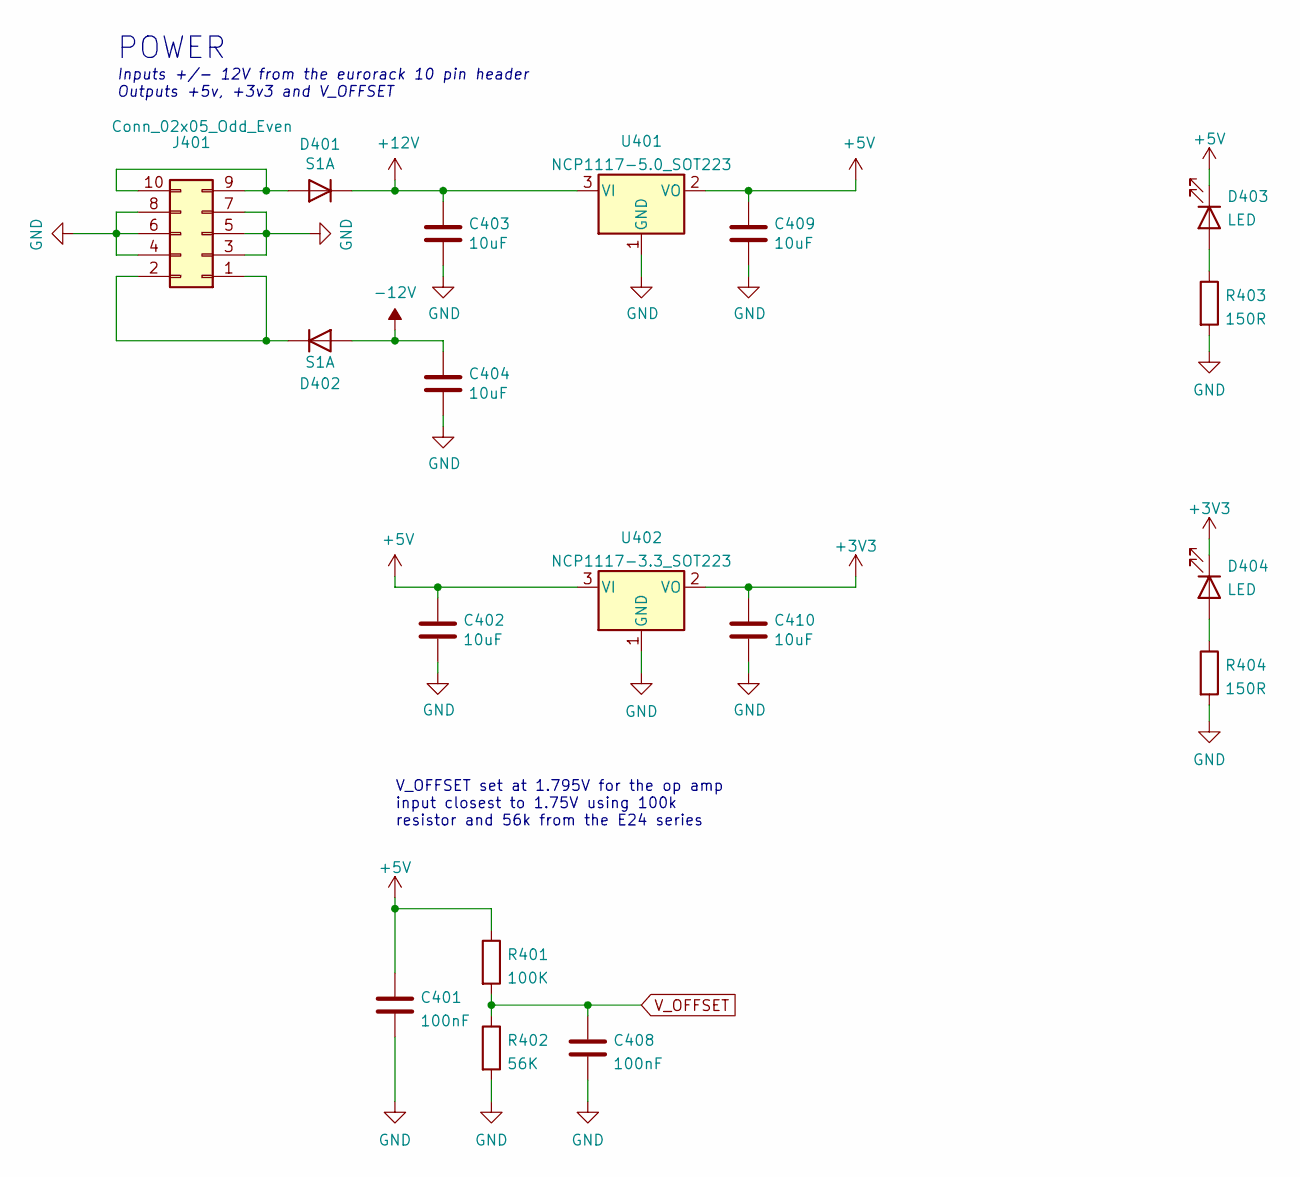
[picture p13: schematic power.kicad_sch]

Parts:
C401, C408: 100nF; C_0805_2012Metric_Pad1.18x1.45mm_HandSolder; Voltage 50V
C402, C403, C404, C409, C410: 10uF; C_0805_2012Metric_Pad1.18x1.45mm_HandSolder; Voltage 50V
D401, D402: S1A; D_SMA
D403, D404: LED; LED_0805_2012Metric_Pad1.15x1.40mm_HandSolder
J401: Conn_02x05_Odd_Even; IDC-Header_2x05_P2.54mm_Horizontal
R401: 100K; R_0805_2012Metric_Pad1.20x1.40mm_HandSolder; Tolerance 1%
R402: 56K; R_0805_2012Metric_Pad1.20x1.40mm_HandSolder; Tolerance 1%
R403, R404: 150R; R_0805_2012Metric_Pad1.20x1.40mm_HandSolder; Tolerance 1%
U401: NCP1117-5.0_SOT223; SOT-223-3_TabPin2; Voltage 5V
U402: NCP1117-3.3_SOT223; SOT-223-3_TabPin2; Voltage 3V3

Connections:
+3V3: C410.1, D404.1 (K), U402.2 (VO); also elsewhere on the board
+5V: C401.1, C402.1, C409.1, D403.1 (K), R401.1, U401.2 (VO), U402.3 (VI); also elsewhere on the board
+12V: C403.1, D401.1 (K), U401.3 (VI); also elsewhere on the board
-12V: C404.1, D402.2 (A); also elsewhere on the board
GND: C401.2, C402.2, C403.2, C404.2, C408.2, C409.2, C410.2, J401.3, J401.4, J401.5, J401.6, J401.7, J401.8, R402.2, R403.2, R404.2, U401.1 (GND), U402.1 (GND); also elsewhere on the board
unnamed: D401.2 (A), J401.9, J401.10
unnamed: D402.1 (K), J401.1, J401.2
unnamed: D403.2 (A), R403.1
unnamed: D404.2 (A), R404.1
V_OFFSET: C408.1, R401.2, R402.1; also elsewhere on the board

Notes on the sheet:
V_OFFSET set at 1.795V for the op amp input closest to 1.75V using 100k resistor and 56k from the E24 series
POWER
Inputs +/- 12V from the eurorack 10 pin header Outputs +5v, +3v3 and V_OFFSET

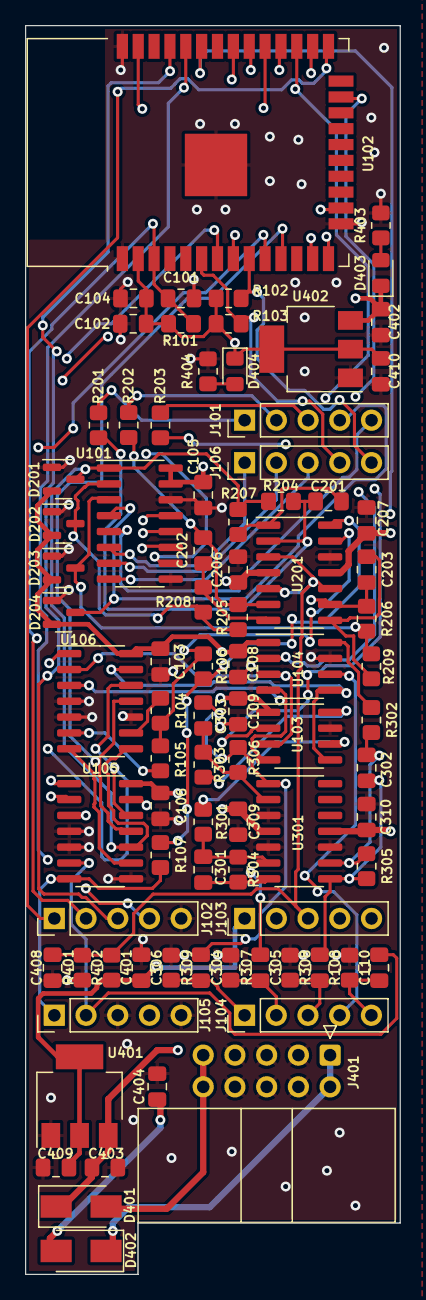
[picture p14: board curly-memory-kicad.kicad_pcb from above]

Board: 4 copper layers, 30.0 x 100.0 mm, 84 parts (0 on the bottom side), 70 nets.

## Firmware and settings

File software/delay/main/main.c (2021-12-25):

/* Blink Example

   This example code is in the Public Domain (or CC0 licensed, at your option.)

   Unless required by applicable law or agreed to in writing, this
   software is distributed on an "AS IS" BASIS, WITHOUT WARRANTIES OR
   CONDITIONS OF ANY KIND, either express or implied.
*/
#include <stdio.h>
#include <stdlib.h>
#include <string.h>
#include "driver/spi_master.h"
#include "sdkconfig.h"
#include "esp_log.h"


#define MISO   12
#define MOSI   13
#define CLK    14
#define RES_CS 15
#define RES2_CS 16

#define A_MISO   19
#define A_MOSI   23
#define A_CLK    18
#define ADC_CS 5
#define A_SPI_HOST  VSPI_HOST
#define CLK_SPEED   1*1000*1000
#define H_SPI_HOST    HSPI_HOST

#define TRANSFER_SIZE 16

static const char TAG[] = "CMD"; // curly-memory-delay tag

spi_device_handle_t spi_dac;
spi_device_handle_t spi_adc;

#define BUF_SIZE  50*1000

uint16_t buf[BUF_SIZE];
uint32_t buf_head;
uint32_t buf_tail;

/*
* Inits the spi line
*/

void init_spi()
{
  ESP_LOGI(TAG, "Initing the SPI bus");
  esp_err_t ret;
  spi_bus_config_t buscfg={
    .miso_io_num=MISO,
    .mosi_io_num=MOSI,
    .sclk_io_num=CLK,
    .quadwp_io_num=-1,
    .quadhd_io_num=-1,
    .max_transfer_sz=TRANSFER_SIZE
  };
  //Initialize the SPI bus
  ret=spi_bus_initialize(H_SPI_HOST, &buscfg, SPI_DMA_CH_AUTO);


  ESP_LOGI(TAG, "Initing the resistor1 spi device");
  spi_device_interface_config_t dac_dev={
    .clock_speed_hz=CLK_SPEED,           //Clock out at 10 MHz
    .mode=0,                                //SPI mode 0
    .spics_io_num=RES_CS,               //CS pin
    .queue_size=7,                          //We want to be able to queue 7 transactions at a time
  };
  ESP_ERROR_CHECK(ret);
  //Attach the LCD to the SPI bus
  ret=spi_bus_add_device(H_SPI_HOST, &dac_dev, &spi_dac);
  ESP_ERROR_CHECK(ret);

  ESP_LOGI(TAG, "Setting up SPI3 (VSPI)");
  spi_bus_config_t a_buscfg={
    .miso_io_num=A_MISO,
    .mosi_io_num=A_MOSI,
    .sclk_io_num=A_CLK,
    .quadwp_io_num=-1,
    .quadhd_io_num=-1,
    .max_transfer_sz=TRANSFER_SIZE
  };
  //Initialize the SPI bus
  ret=spi_bus_initialize(A_SPI_HOST, &a_buscfg, SPI_DMA_CH_AUTO);


  ESP_LOGI(TAG, "Initing the adc spi device");


  spi_device_interface_config_t adc_dev={
    .clock_speed_hz=CLK_SPEED,           //Clock out at 10 MHz
    .mode=1,                                //SPI mode 0
    .spics_io_num=ADC_CS,               //CS pin
    .queue_size=7,                          //We want to be able to queue 7 transactions at a time
  };
  ESP_ERROR_CHECK(ret);
  //Attach the LCD to the SPI bus
  ret=spi_bus_add_device(A_SPI_HOST, &adc_dev, &spi_adc);
  ESP_ERROR_CHECK(ret);
}

void send_spi(spi_device_handle_t device, uint8_t cmd, uint8_t value)
{
  ESP_LOGI(TAG, "Sending value to spi : %d", value);
  static spi_transaction_t trans;
  memset(&trans, 0, sizeof(spi_transaction_t));
  trans.length = TRANSFER_SIZE;
  trans.flags = SPI_TRANS_USE_TXDATA | SPI_TRANS_USE_RXDATA;
  trans.tx_data[0] = cmd;
  trans.tx_data[1] = value;
  spi_device_transmit(device, &trans);
  ESP_LOGI(TAG, "Rx value from spi : %d %d %d %d %d", trans.rxlength, trans.rx_data[0], trans.rx_data[1], trans.rx_data[2], trans.rx_data[3]);

}

uint16_t read_adc(uint8_t single_diff, uint8_t channel)
{
  static spi_transaction_t trans;
//   memset(&trans, 0, sizeof(spi_transaction_t));
  trans.length = 24;
  trans.flags = SPI_TRANS_USE_TXDATA | SPI_TRANS_USE_RXDATA;
  trans.tx_data[0] = 1;
  trans.tx_data[1] = (single_diff << 7) | (channel << 4);
  trans.tx_data[3] = 0;
//   ESP_LOGI(TAG, "Sending value to spi : %d %d %d %d", trans.tx_data[0], trans.tx_data[1], trans.tx_data[2], trans.tx_data[3]);
  spi_device_transmit(spi_adc, &trans);
  uint16_t adc = ((trans.rx_data[1] & 3) << 8) + trans.rx_data[2];
//   ESP_LOGI(TAG, "Receiving value from spi : %d - %d %d %d %d", adc, trans.rx_data[0], trans.rx_data[1], trans.rx_data[2], trans.rx_data[3]);
  return adc;
}

void send_dac(uint8_t A_B, uint8_t gain, uint8_t shdn, uint16_t data)
{
//   ESP_LOGI(TAG, "Sending value to spi : %d", data);
  static spi_transaction_t trans;
//   memset(&trans, 0, sizeof(spi_transaction_t));
  trans.length = 16;
  trans.flags = SPI_TRANS_USE_TXDATA;
  trans.tx_data[0] = (A_B << 7) | (gain << 5) | (shdn << 4) | (data >> 4);
  trans.tx_data[1] = data << 4;
  spi_device_transmit(spi_dac, &trans);
//   ESP_LOGI(TAG, "Rx value from spi : %d %X %X", trans.rxlength, trans.tx_data[0], trans.tx_data[1]);

}

uint16_t buf_pop()
{
  uint16_t value = buf[buf_tail];
  buf[buf_tail] = 0;
  buf_tail++;
  if (buf_tail == BUF_SIZE)
  {
    buf_tail = 0;
  }
  return value;
}


void buf_add_delay(uint16_t value, uint16_t delay, uint8_t decay)
{
  uint16_t delay_value = value / decay;
  uint32_t delay_index = buf_tail + delay;
  if (delay_index >= BUF_SIZE)
  {
    delay_index = delay_index - BUF_SIZE;
  }
  buf[delay_index] = buf[delay_value] + delay_value;
}



void app_main(void)
{
  init_spi();

  uint8_t count1 = 0;
  uint8_t value = 0;

  memset(&buf, 0, sizeof(buf));
  buf_head = 0;
  buf_tail = 0;

  uint16_t repeats = 10;
  uint16_t depth = 500;

  while(1) {
    count1++;

    // read value from adc as 12 bit value
    value = read_adc(1, 0);
    for (uint8_t i = 1; i <= repeats; i++)
    {
       buf_add_delay(value, i*depth, i+1);
    }

    // send value from adc to dac as 12 bit value
    send_dac(0, 1, 1, buf_pop());

  }
}

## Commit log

2021-12-12 added initial commit for the kicad hardware, added component list and osc_in circuit picture
    [curly-memory-kicad.kicad_pcb, curly-memory-kicad.sch, osc_input.sch]
2021-12-23 hardware update to relfect latest version of projectm gitignore updated to ignore *-bak files
    [curly-memory-kicad.sch, input.sch, osc_input.sch]
2021-12-29 hardware schematic updated to kicad6, extra components added: 2nd digital pot, rotary encoder, tactile switch x2, wet/dry mix going to out1
    [curly-memory-kicad.kicad_sch, input.kicad_sch]
2022-01-02 output + input op amps added, simuatlion added to sim folder
    [curly-memory-kicad.kicad_sch, input.kicad_sch, output.kicad_sch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]
2022-01-06 schematic updated with component fields on more components
    [curly-memory-kicad.kicad_sch, input.kicad_sch, output.kicad_sch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]
2022-01-08 all components have part numbers
    [curly-memory-kicad.kicad_sch, input.kicad_sch, output.kicad_sch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]
2022-01-09 interface board added
    [curly-memory-interface-board.kicad_pcb, curly-memory-interface-board.kicad_sch, curly-memory-interface-board.sch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]
2022-01-11 all components placed on the main board
    [curly-memory-interface-board.kicad_pcb, curly-memory-interface-board.kicad_sch, curly-memory-kicad.kicad_pcb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]
2022-01-15 more pcb tracked
    [curly-memory-assembly.FCStd, curly-memory-face-plate-a0.step, curly-memory-face-plate.kicad_pcb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]
2022-01-15 more pcb tracked- again
    [curly-memory-kicad.kicad_pcb]
2022-01-15 silkscreen lined up lovely
    [curly-memory-assembly.FCStd, curly-memory-kicad.kicad_pcb, curly-memory-kicad.kicad_sch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]
2022-01-15 interface board tracked and silkscreen sorted
    [curly-memory-interface-board 3.kicad_sch, curly-memory-interface-board.kicad_pcb]
2022-01-15 all hardware finished
    [curly-memory-assembly.FCStd, curly-memory-face-plate.kicad_pcb, curly-memory-interface-board.kicad_pcb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]
2022-01-16 gerbers genearted and mf/mfpn added for main board for build
    [curly-memory-face-plate-B_Cu.gbr, curly-memory-face-plate-B_Mask.gbr, curly-memory-face-plate-B_Paste.gbr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]
2022-01-24 pcbs sent off to pcbway for issue A
    [cm-main-bom.csv, cm-main-xy.csv, curly-memory-assembly 3.FCStd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]
2022-01-24 put the brackets the right way round
